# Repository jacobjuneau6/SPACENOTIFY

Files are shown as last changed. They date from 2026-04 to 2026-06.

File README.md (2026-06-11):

# SPACENOTIFY
SPACENOTIFY is a desktop dashboard that shows all space related activites including Launches, Landing and EVAs through the Launch Library 2 API.
# WHY
I designed SPACENOTIFY because I often can not look at my phone to check upcoming launches and I never want to miss one so this can sit on mydesk and as it has no controls can not be a distraction like a phone.
# Pictures
Final Front
Final Back
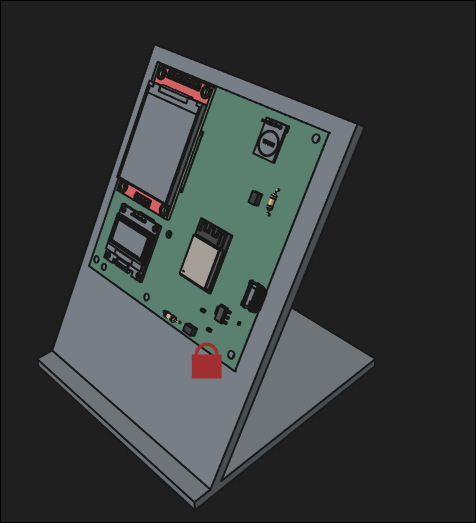
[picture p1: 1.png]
Assembly

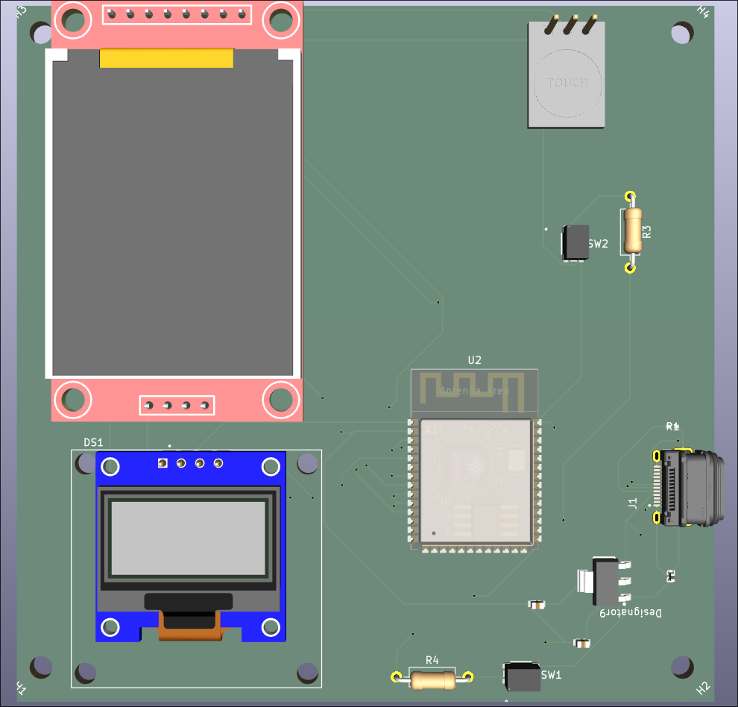
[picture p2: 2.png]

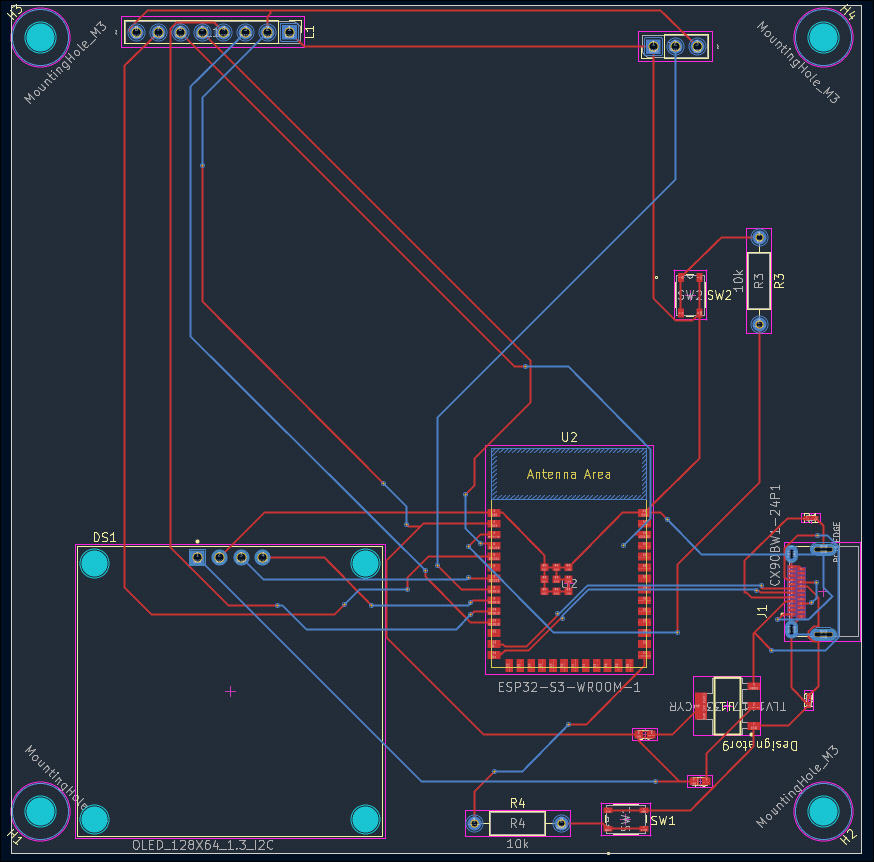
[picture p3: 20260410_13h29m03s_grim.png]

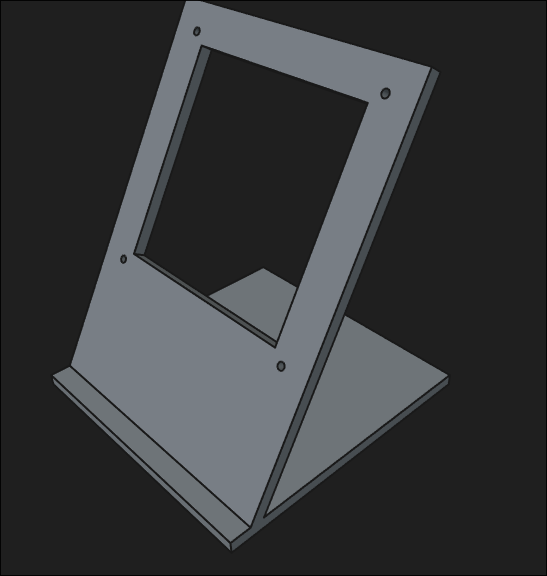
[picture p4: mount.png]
Mount

# BOM
| Name | Purpose | Quantity | Total Cost (USD) | Link | Distributor |
| --- | --- | --- | --- | --- | --- |
| GRM188R60J106KE47D 10uF capacitor | power filtering | 2 | 0.22 | https://www.digikey.com/en/products/detail/murata-electronics/GRM188R60J106KE47D/5797506 | Digikey |
| RC0402FR-075K1L 5.1k resistor | controll usb-c pd voltage | 2 | 0.20 | https://www.digikey.com/en/products/detail/yageo/RC0402FR-075K1L/726624 | Digikey |
| CX90BW1-24P1 USB c connector | power + data | 1 | 2.99 | https://www.digikey.com/en/products/detail/hirose-electric-co-ltd/CX90BW1-24P1/22566049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 | Digikey |
| SKRPABE010 button | to trigger boot and reset the esp32 | 2 | 0.42 | https://www.digikey.com/en/products/detail/alps-alpine/SKRPABE010/18768948 | Digikey |
| TLV1117-33IDCYR | LDO voltage regulator | 1 | 0.45 | https://www.digikey.com/en/products/detail/texas-instruments/TLV1117-33IDCYR/1216719 | Digikey |
| ESP32-S3-WROOM-1-N8R2 | Main MCU | 1 | 5.71 | https://www.digikey.com/en/products/detail/espressif-systems/ESP32-S3-WROOM-1-N8R2/15200058 | Digikey |
| Touch sensor | to allow UI interaction | 10 | 1.66 | https://www.aliexpress.us/item/3256806056841370.html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 | Aliexpress |
| 1.8in LCD | Displays main info | 1 | 2.88 | https://www.aliexpress.us/item/3256805953674718.html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 | Aliexpress |
| PCB | Holds the display and esp32 | 1 | 5.00 |  | PCBWAY |
| I2c display | shows the info | 1 | 1.99 | https://www.aliexpress.us/item/3256805899077405.html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 | Aliexpress |

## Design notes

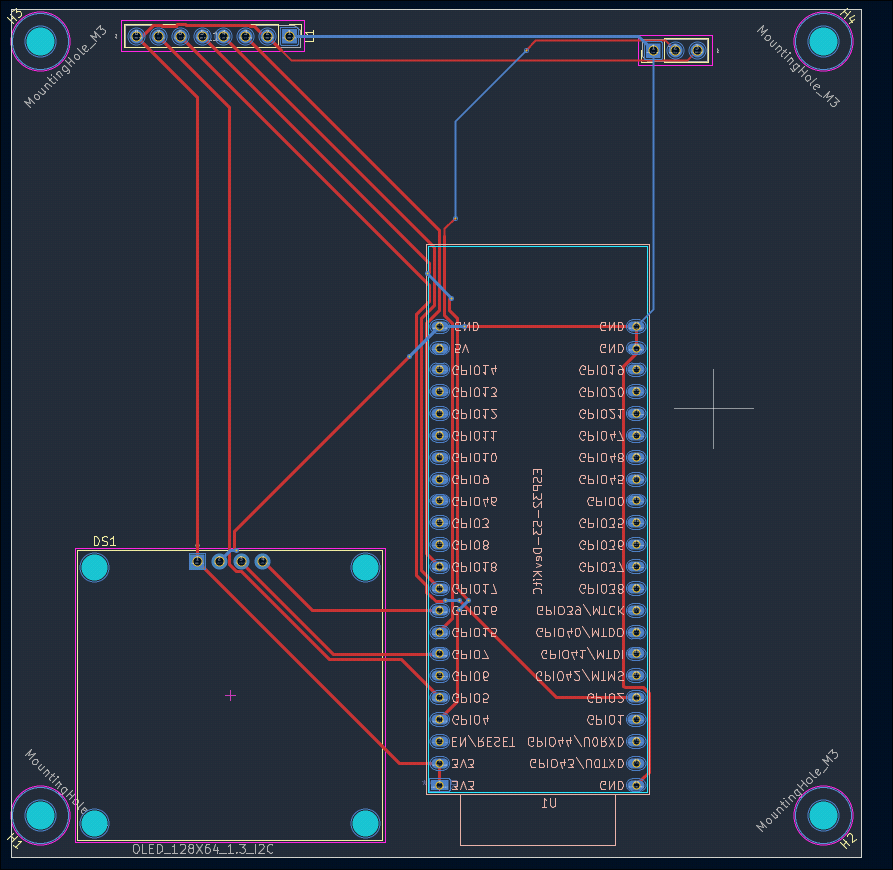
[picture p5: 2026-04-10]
20260410_11h46m12s_grim.png

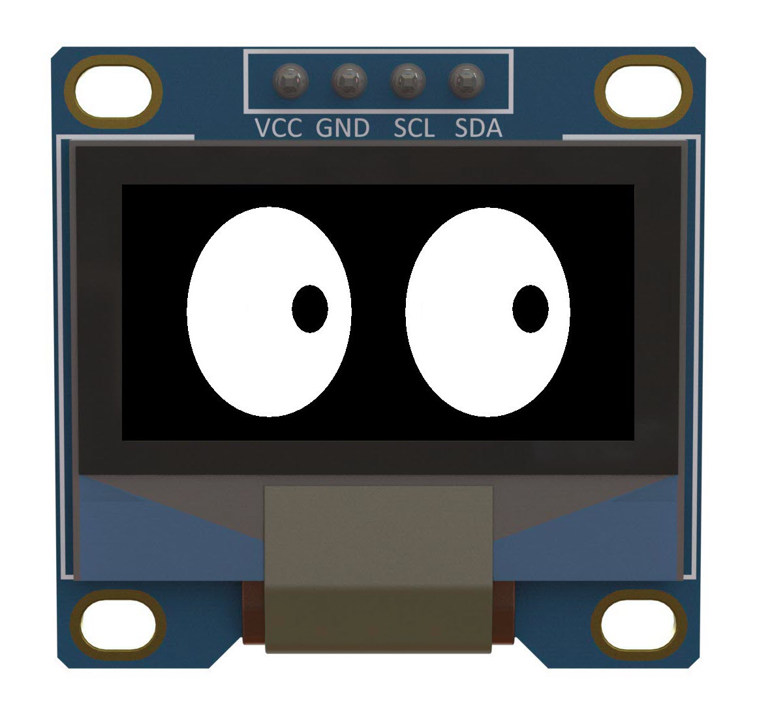
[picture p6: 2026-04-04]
v1/symbols/KiCad-SSD1306-128x64-0.1/oled-128-x-64-display-1.snapshot.15/OLED Eyes SLIDE.JPG

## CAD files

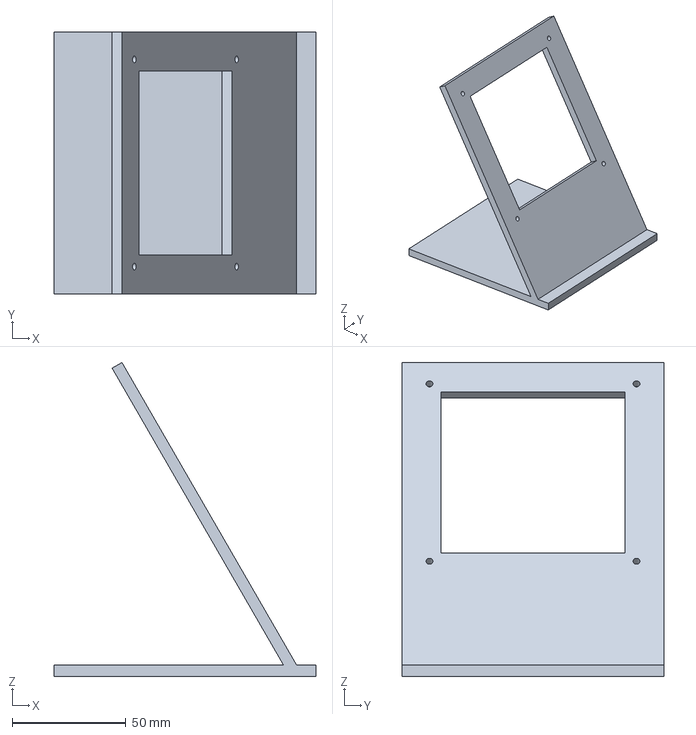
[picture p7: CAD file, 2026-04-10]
CAD/Base-v2.FCStd
115.0 x 115.0 x 138.0 mm

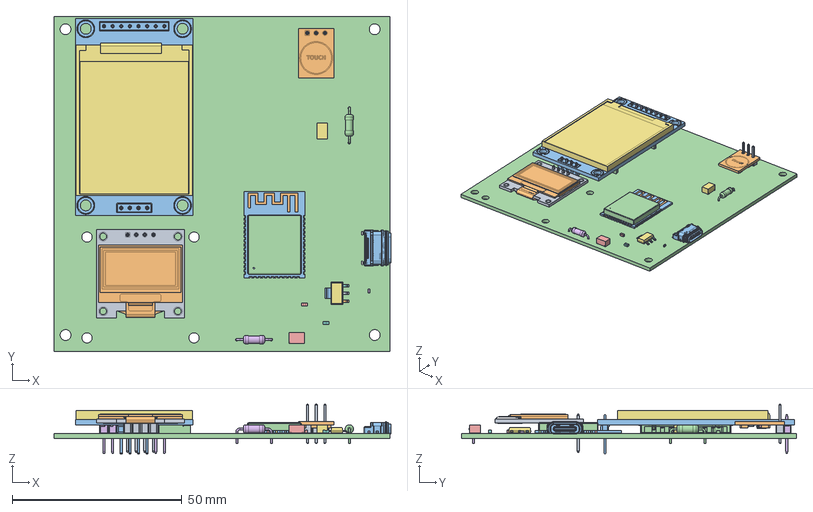
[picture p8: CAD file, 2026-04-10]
PCB.FCStd
99.2 x 98.6 x 14.6 mm
PinHeader_1x03_P2.54mm_Vertical
touch button TTP223
Board~fHK2
TopSilkscreen~fHK2
BottomSilkscreen~fHK2
R0603~R0603~fHK2
R0603~R0603~fHK001
R0603~R0603~fHK002
R0603~R0603~fHK003
SOT-23-3_L2.9-W1.3-P1.90-LS2.4-BR~SOT-23-3P_L2.9-W1.3-H1.0-LS2.4-P0.95~fHK2
HDR-TH_4P-P2.54-V-M~HDR-TH_4P-P2.54-M-LI-1X4P~fHK2
SD-CARD-SMD_SD-CARD-11P~SD-CARD-SMD_SD-CARD-11P~fHK2
C0603~C0603_L1.6-W0.8-H0.8~fHK2
HDR-TH_8P-P2.54-V-M~HDR-TH_8P-P2.54-V-M~fHK2
C0201_20210301.STEP^C0201_20210301.STEP_Submodel-C0201_part_DesignRootModel_PCB_ESP32-S3-WROOM-1_V1(2)_PCB_ESP32-S3-WROOM-1_V1
L0201_20210301.STEP^L0201_20210301.STEP_Submodel-L0201_part_DesignRootModel_PCB_ESP32-S3-WROOM-1_V1(2)_PCB_ESP32-S3-WROOM-1_V1
C0402_20210301.STEP^C0402_20210301.STEP_Submodel-C0402_part_DesignRootModel_PCB_ESP32-S3-WROOM-1_V1(2)_PCB_ESP32-S3-WROOM-1_V1
R0201_20210301.STEP^R0201_20210301.STEP_Submodel-R0201_part_DesignRootModel_PCB_ESP32-S3-WROOM-1_V1(2)_PCB_ESP32-S3-WROOM-1_V1
R0201_20210301.STEP^R0201_20210301.STEP_Submodel-R0201_part_DesignRootModel_PCB_ESP32-S3-WROOM-1_V1(2)_PCB_ESP32-S3-WROOM-1_V001
R0201_20210301.STEP^R0201_20210301.STEP_Submodel-R0201_part_DesignRootModel_PCB_ESP32-S3-WROOM-1_V1(2)_PCB_ESP32-S3-WROOM-1_V002
R0201_20210301.STEP^R0201_20210301.STEP_Submodel-R0201_part_DesignRootModel_PCB_ESP32-S3-WROOM-1_V1(2)_PCB_ESP32-S3-WROOM-1_V003
R0201_20210301.STEP^R0201_20210301.STEP_Submodel-R0201_part_DesignRootModel_PCB_ESP32-S3-WROOM-1_V1(2)_PCB_ESP32-S3-WROOM-1_V004
R0201_20210301.STEP^R0201_20210301.STEP_Submodel-R0201_part_DesignRootModel_PCB_ESP32-S3-WROOM-1_V1(2)_PCB_ESP32-S3-WROOM-1_V005
R0201_20210301.STEP^R0201_20210301.STEP_Submodel-R0201_part_DesignRootModel_PCB_ESP32-S3-WROOM-1_V1(2)_PCB_ESP32-S3-WROOM-1_V006
R0201_20210301.STEP^R0201_20210301.STEP_Submodel-R0201_part_DesignRootModel_PCB_ESP32-S3-WROOM-1_V1(2)_PCB_ESP32-S3-WROOM-1_V007
L0201_20210301.STEP^L0201_20210301.STEP_Submodel-L0201_part_DesignRootModel_PCB_ESP32-S3-WROOM-1_V1(2)_PCB_ESP32-S3-WROOM-1_V001
L0201_20210301.STEP^L0201_20210301.STEP_Submodel-L0201_part_DesignRootModel_PCB_ESP32-S3-WROOM-1_V1(2)_PCB_ESP32-S3-WROOM-1_V002
C0201_20210301.STEP^C0201_20210301.STEP_Submodel-C0201_part_DesignRootModel_PCB_ESP32-S3-WROOM-1_V1(2)_PCB_ESP32-S3-WROOM-1_V001
C0201_20210301.STEP^C0201_20210301.STEP_Submodel-C0201_part_DesignRootModel_PCB_ESP32-S3-WROOM-1_V1(2)_PCB_ESP32-S3-WROOM-1_V002
C0201_20210301.STEP^C0201_20210301.STEP_Submodel-C0201_part_DesignRootModel_PCB_ESP32-S3-WROOM-1_V1(2)_PCB_ESP32-S3-WROOM-1_V003
C0201_20210301.STEP^C0201_20210301.STEP_Submodel-C0201_part_DesignRootModel_PCB_ESP32-S3-WROOM-1_V1(2)_PCB_ESP32-S3-WROOM-1_V004
C0201_20210301.STEP^C0201_20210301.STEP_Submodel-C0201_part_DesignRootModel_PCB_ESP32-S3-WROOM-1_V1(2)_PCB_ESP32-S3-WROOM-1_V005
C0201_20210301.STEP^C0201_20210301.STEP_Submodel-C0201_part_DesignRootModel_PCB_ESP32-S3-WROOM-1_V1(2)_PCB_ESP32-S3-WROOM-1_V006
C0201_20210301.STEP^C0201_20210301.STEP_Submodel-C0201_part_DesignRootModel_PCB_ESP32-S3-WROOM-1_V1(2)_PCB_ESP32-S3-WROOM-1_V007
C0201_20210301.STEP^C0201_20210301.STEP_Submodel-C0201_part_DesignRootModel_PCB_ESP32-S3-WROOM-1_V1(2)_PCB_ESP32-S3-WROOM-1_V008
C0201_20210301.STEP^C0201_20210301.STEP_Submodel-C0201_part_DesignRootModel_PCB_ESP32-S3-WROOM-1_V1(2)_PCB_ESP32-S3-WROOM-1_V009
C0201_20210301.STEP^C0201_20210301.STEP_Submodel-C0201_part_DesignRootModel_PCB_ESP32-S3-WROOM-1_V1(2)_PCB_ESP32-S3-WROOM-1_V010
C0201_20210301.STEP^C0201_20210301.STEP_Submodel-C0201_part_DesignRootModel_PCB_ESP32-S3-WROOM-1_V1(2)_PCB_ESP32-S3-WROOM-1_V011
C0201_20210301.STEP^C0201_20210301.STEP_Submodel-C0201_part_DesignRootModel_PCB_ESP32-S3-WROOM-1_V1(2)_PCB_ESP32-S3-WROOM-1_V012
C0201_20210301.STEP^C0201_20210301.STEP_Submodel-C0201_part_DesignRootModel_PCB_ESP32-S3-WROOM-1_V1(2)_PCB_ESP32-S3-WROOM-1_V013
trace_1^Submodel-MINI-ANT-TYPEB_668419613_part_DesignRootModel_PCB_ESP32-S3-WROOM-1_V1(2)_PCB_ESP32-S3-WROOM-1_V1
DFN1006.STEP^DFN1006.STEP_Submodel-SOD882_part_DesignRootModel_PCB_ESP32-S3-WROOM-1_V1(2)_PCB_ESP32-S3-WROOM-1_V1
SOP8_rev1_20210308.STEP^SOP8_rev1_20210308.STEP_Submodel-SOP8_1P27_6P6_part_DesignRootModel_PCB_ESP32-S3-WROOM-1_V1(2)_PCB_ESP32-S3-WROOM-1_V1
XTAL3225_20210301.STEP^XTAL3225_20210301.STEP_Submodel-XTAL3225_part_DesignRootModel_PCB_ESP32-S3-WROOM-1_V1(2)_PCB_ESP32-S3-WROOM-1_V1
ESP32-S3_20210301.STEP^ESP32-S3_20210301.STEP_Submodel-QFN56_0P4_7_part_DesignRootModel_PCB_ESP32-S3-WROOM-1_V1(2)_PCB_ESP32-S3-WROOM-1_V1
uid__4-128^DesignRootModel_PCB_ESP32-S3-WROOM-1_V1(2)_PCB_ESP32-S3-WROOM-1_V1
uid__4-129^DesignRootModel_PCB_ESP32-S3-WROOM-1_V1(2)_PCB_ESP32-S3-WROOM-1_V1
uid__4-130^DesignRootModel_PCB_ESP32-S3-WROOM-1_V1(2)_PCB_ESP32-S3-WROOM-1_V1
uid__4-149^DesignRootModel_PCB_ESP32-S3-WROOM-1_V1(2)_PCB_ESP32-S3-WROOM-1_V1
uid__4-150^DesignRootModel_PCB_ESP32-S3-WROOM-1_V1(2)_PCB_ESP32-S3-WROOM-1_V1
uid__4-151^DesignRootModel_PCB_ESP32-S3-WROOM-1_V1(2)_PCB_ESP32-S3-WROOM-1_V1
uid__4-167^DesignRootModel_PCB_ESP32-S3-WROOM-1_V1(2)_PCB_ESP32-S3-WROOM-1_V1
uid__4-168^DesignRootModel_PCB_ESP32-S3-WROOM-1_V1(2)_PCB_ESP32-S3-WROOM-1_V1
uid__4-169^DesignRootModel_PCB_ESP32-S3-WROOM-1_V1(2)_PCB_ESP32-S3-WROOM-1_V1
uid__1-279^DesignRootModel_PCB_ESP32-S3-WROOM-1_V1(2)_PCB_ESP32-S3-WROOM-1_V1
uid__1-280^DesignRootModel_PCB_ESP32-S3-WROOM-1_V1(2)_PCB_ESP32-S3-WROOM-1_V1
uid__1-292^DesignRootModel_PCB_ESP32-S3-WROOM-1_V1(2)_PCB_ESP32-S3-WROOM-1_V1
uid__1-298^DesignRootModel_PCB_ESP32-S3-WROOM-1_V1(2)_PCB_ESP32-S3-WROOM-1_V1
uid__1-299^DesignRootModel_PCB_ESP32-S3-WROOM-1_V1(2)_PCB_ESP32-S3-WROOM-1_V1
uid__1-300^DesignRootModel_PCB_ESP32-S3-WROOM-1_V1(2)_PCB_ESP32-S3-WROOM-1_V1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

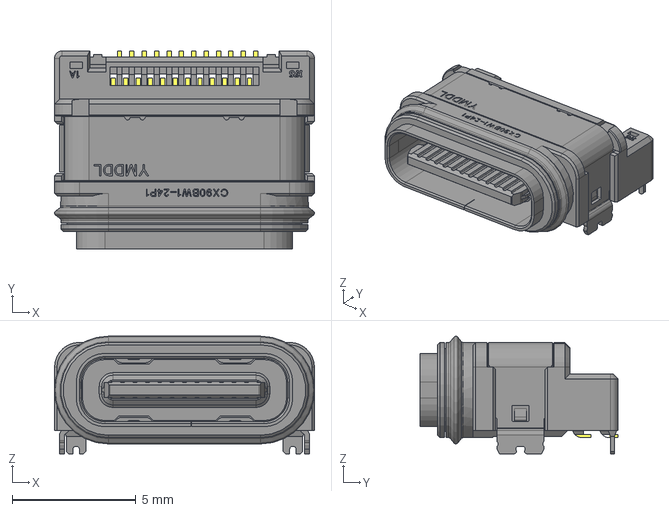
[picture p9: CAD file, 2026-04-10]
v1/symbols/CX90BW1-24P1/CX90BW1-24P1.step
10.5 x 8.00 x 4.75 mm

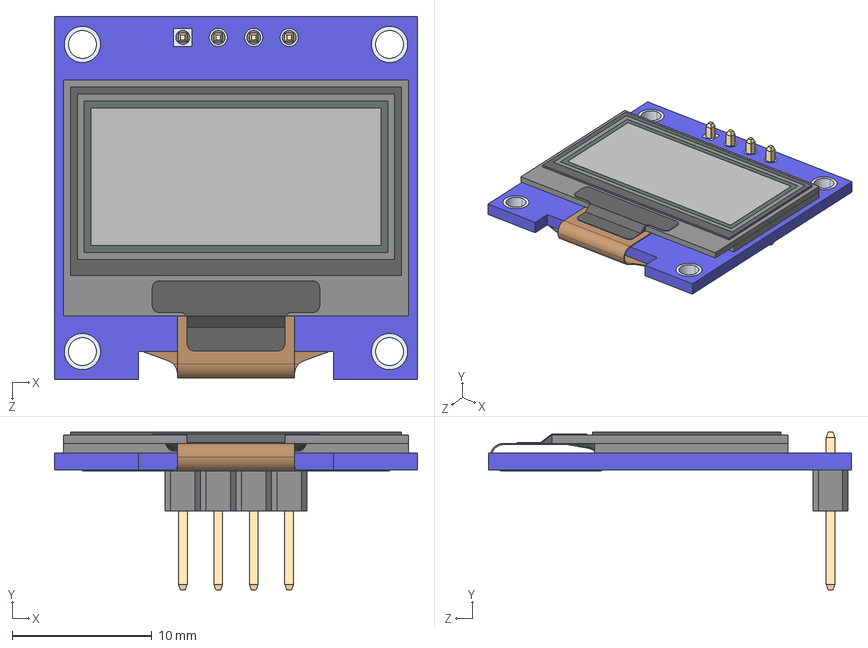
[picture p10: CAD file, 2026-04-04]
v1/symbols/DM-OLED096-636/DM-OLED096-636.step
26.0 x 11.3 x 26.0 mm
DM-OLED096-636_Module
DM-OLED096-636_Panel

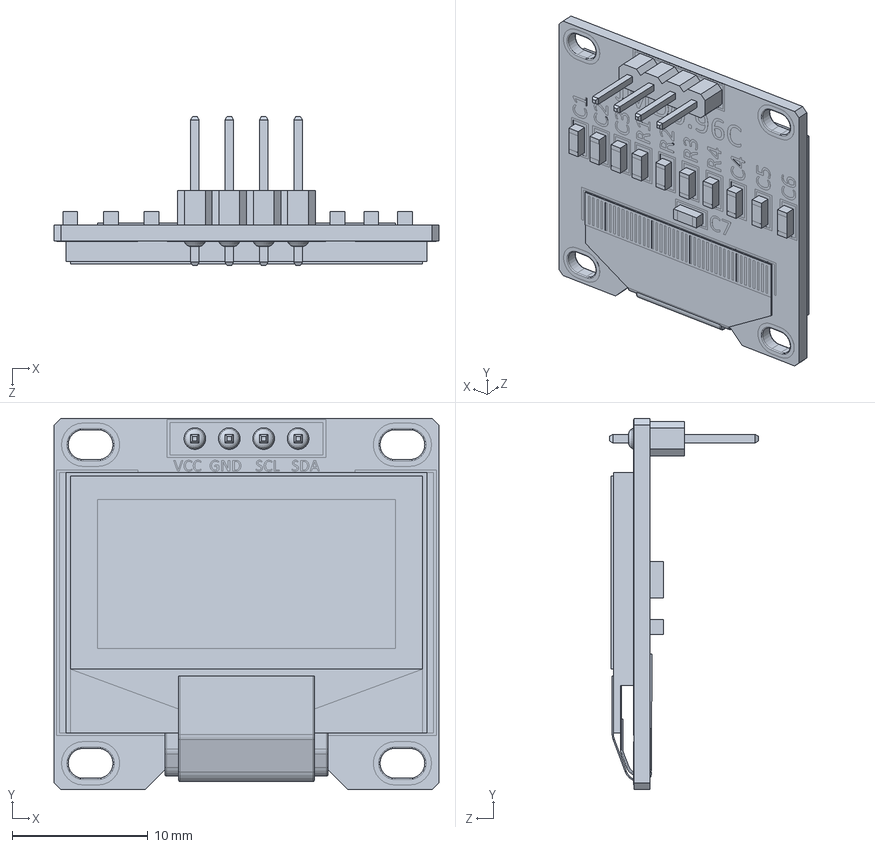
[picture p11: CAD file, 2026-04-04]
v1/symbols/KiCad-SSD1306-128x64-0.1/oled-128-x-64-display-1.snapshot.15/OLED Display 128x64.SLDPRT
28.4 x 27.4 x 11.0 mm

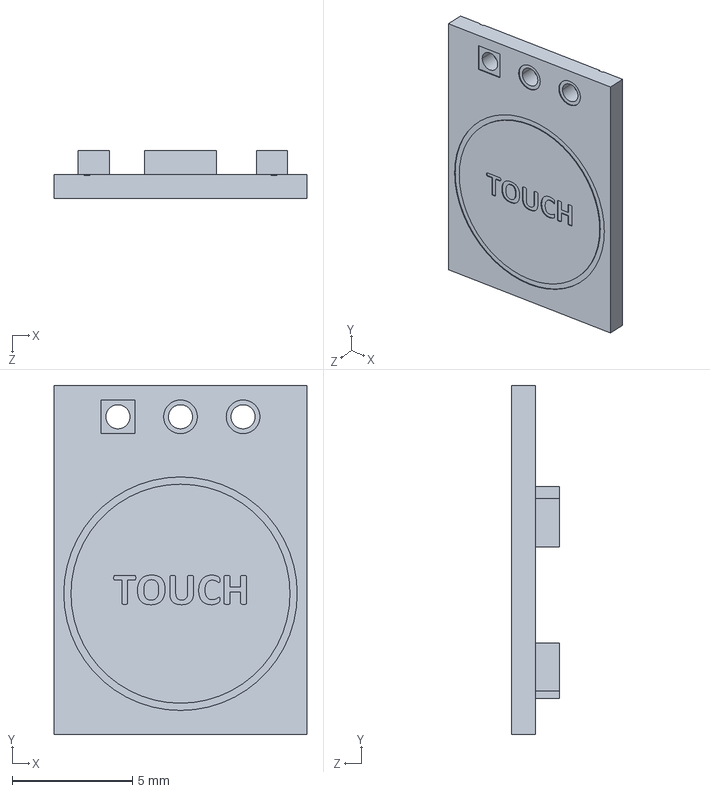
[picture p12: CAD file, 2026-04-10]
v1/symbols/touch button TTP223.STEP
10.5 x 14.5 x 2.00 mm

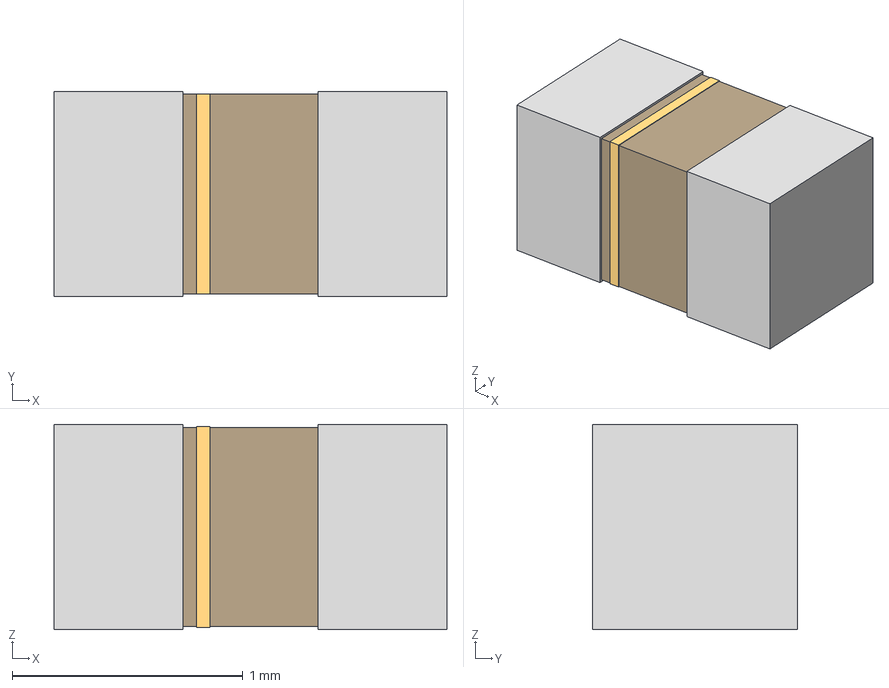
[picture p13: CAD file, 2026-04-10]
v1/symbols/ul_GRM188R60J106KE47D/CAP_GRM188_1608_MUR.step
1.70 x 0.888 x 0.889 mm

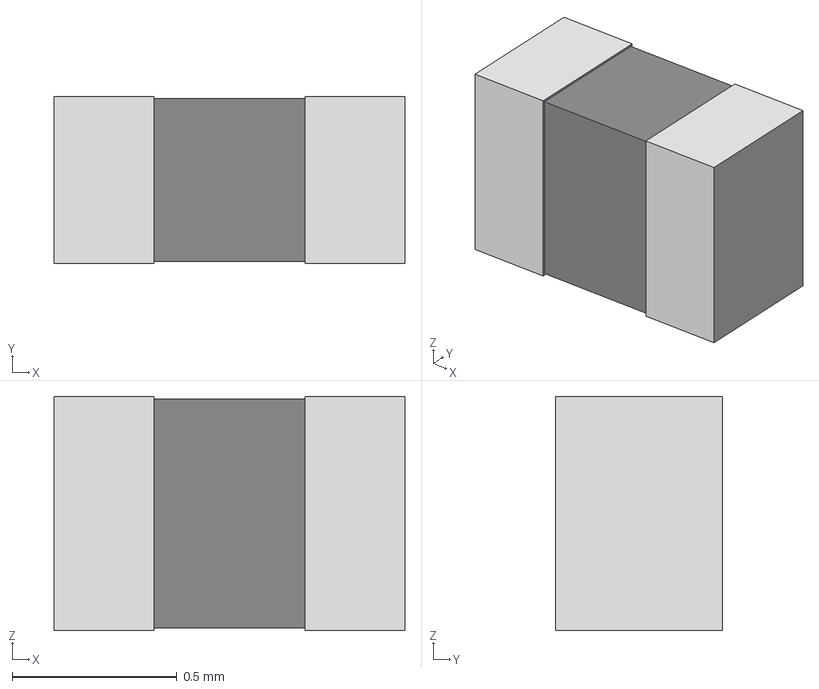
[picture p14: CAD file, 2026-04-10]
v1/symbols/ul_RC0402FR-075K1L/RC0402N_YAG.step
1.07 x 0.508 x 0.711 mm

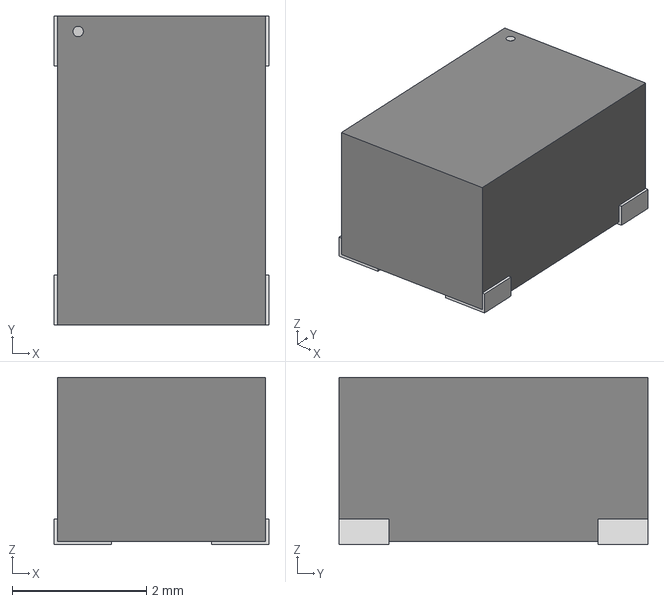
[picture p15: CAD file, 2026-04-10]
v1/symbols/ul_SKRPABE010/SW4_SKRPABE010_ALPS.step
3.20 x 4.60 x 2.49 mm

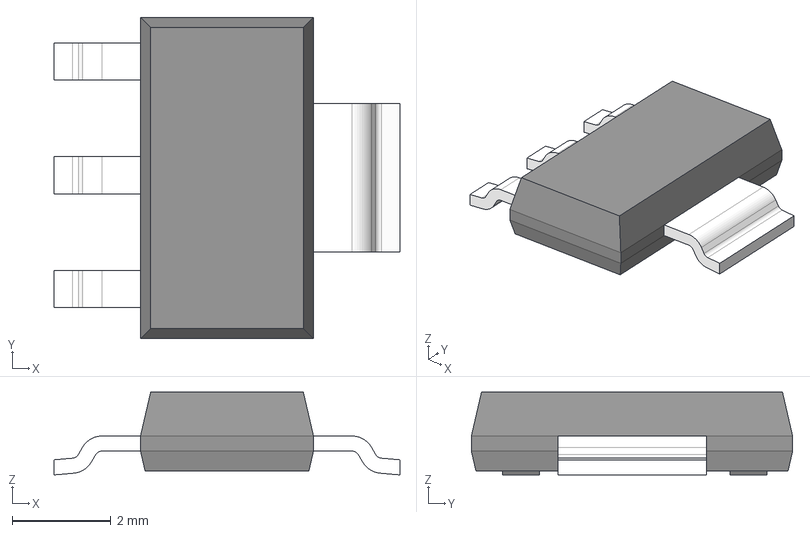
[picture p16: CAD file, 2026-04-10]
v1/symbols/ul_TLV1117-33IDCYR/DCY0004A.stp
7.00 x 6.50 x 1.68 mm
BODY-SOT
LEAD-SOT x 3
LEAD-SOT-WIDE
PIN1-ID

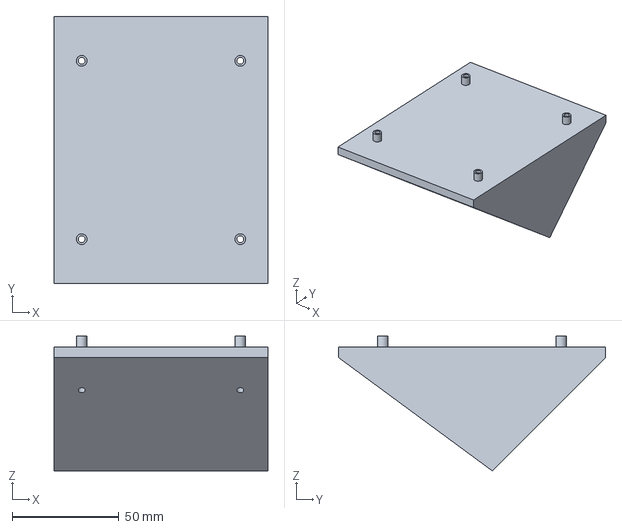
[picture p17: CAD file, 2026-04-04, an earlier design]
CAD/Base.FCStd
100.0 x 125.0 x 63.0 mm

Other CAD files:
CAD/Assembly.FCStd
CAD/Base-v2-Body.step
CAD/PCB.FCStd
v1/symbols/KiCad-SSD1306-128x64-0.1/oled-128-x-64-display-1.snapshot.15/OLED Display 128x64.STL

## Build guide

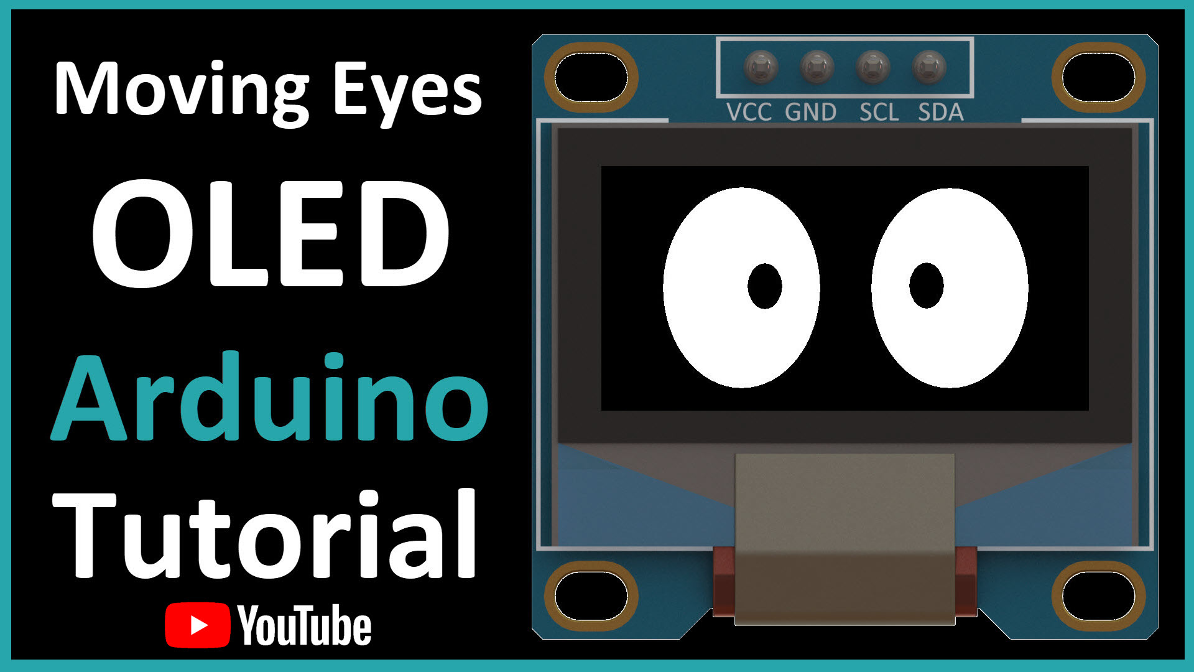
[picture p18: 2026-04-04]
v1/symbols/KiCad-SSD1306-128x64-0.1/oled-128-x-64-display-1.snapshot.15/YouTube OLED Moving Eyes Arduino Tutorial.JPG

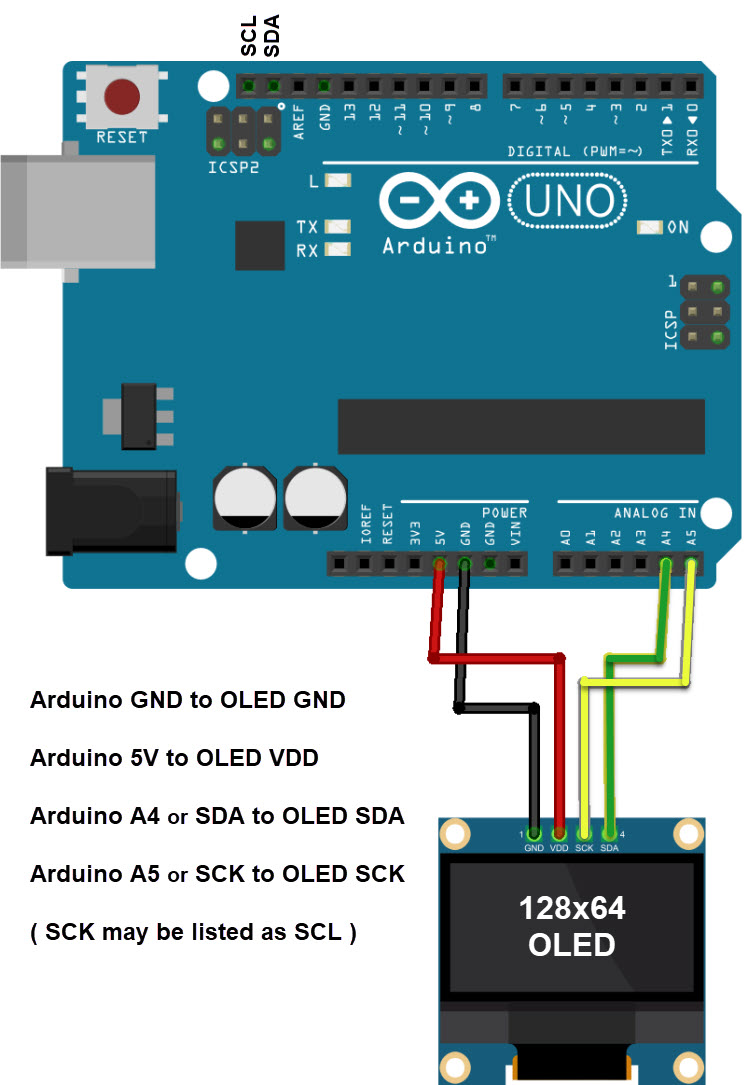
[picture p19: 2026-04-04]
v1/symbols/KiCad-SSD1306-128x64-0.1/oled-128-x-64-display-1.snapshot.15/Arduino Wiring to OLED I2C.jpg

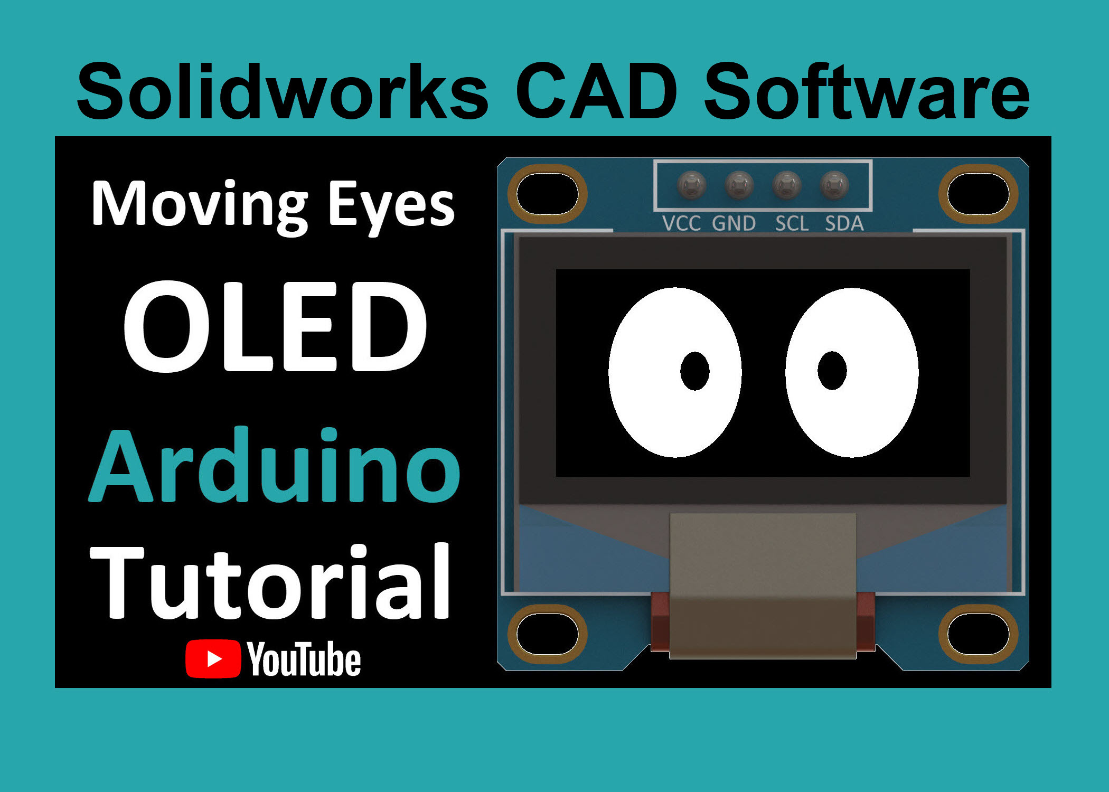
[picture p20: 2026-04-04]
v1/symbols/KiCad-SSD1306-128x64-0.1/oled-128-x-64-display-1.snapshot.15/YouTube OLED Eyes Arduino Tutorial.JPG

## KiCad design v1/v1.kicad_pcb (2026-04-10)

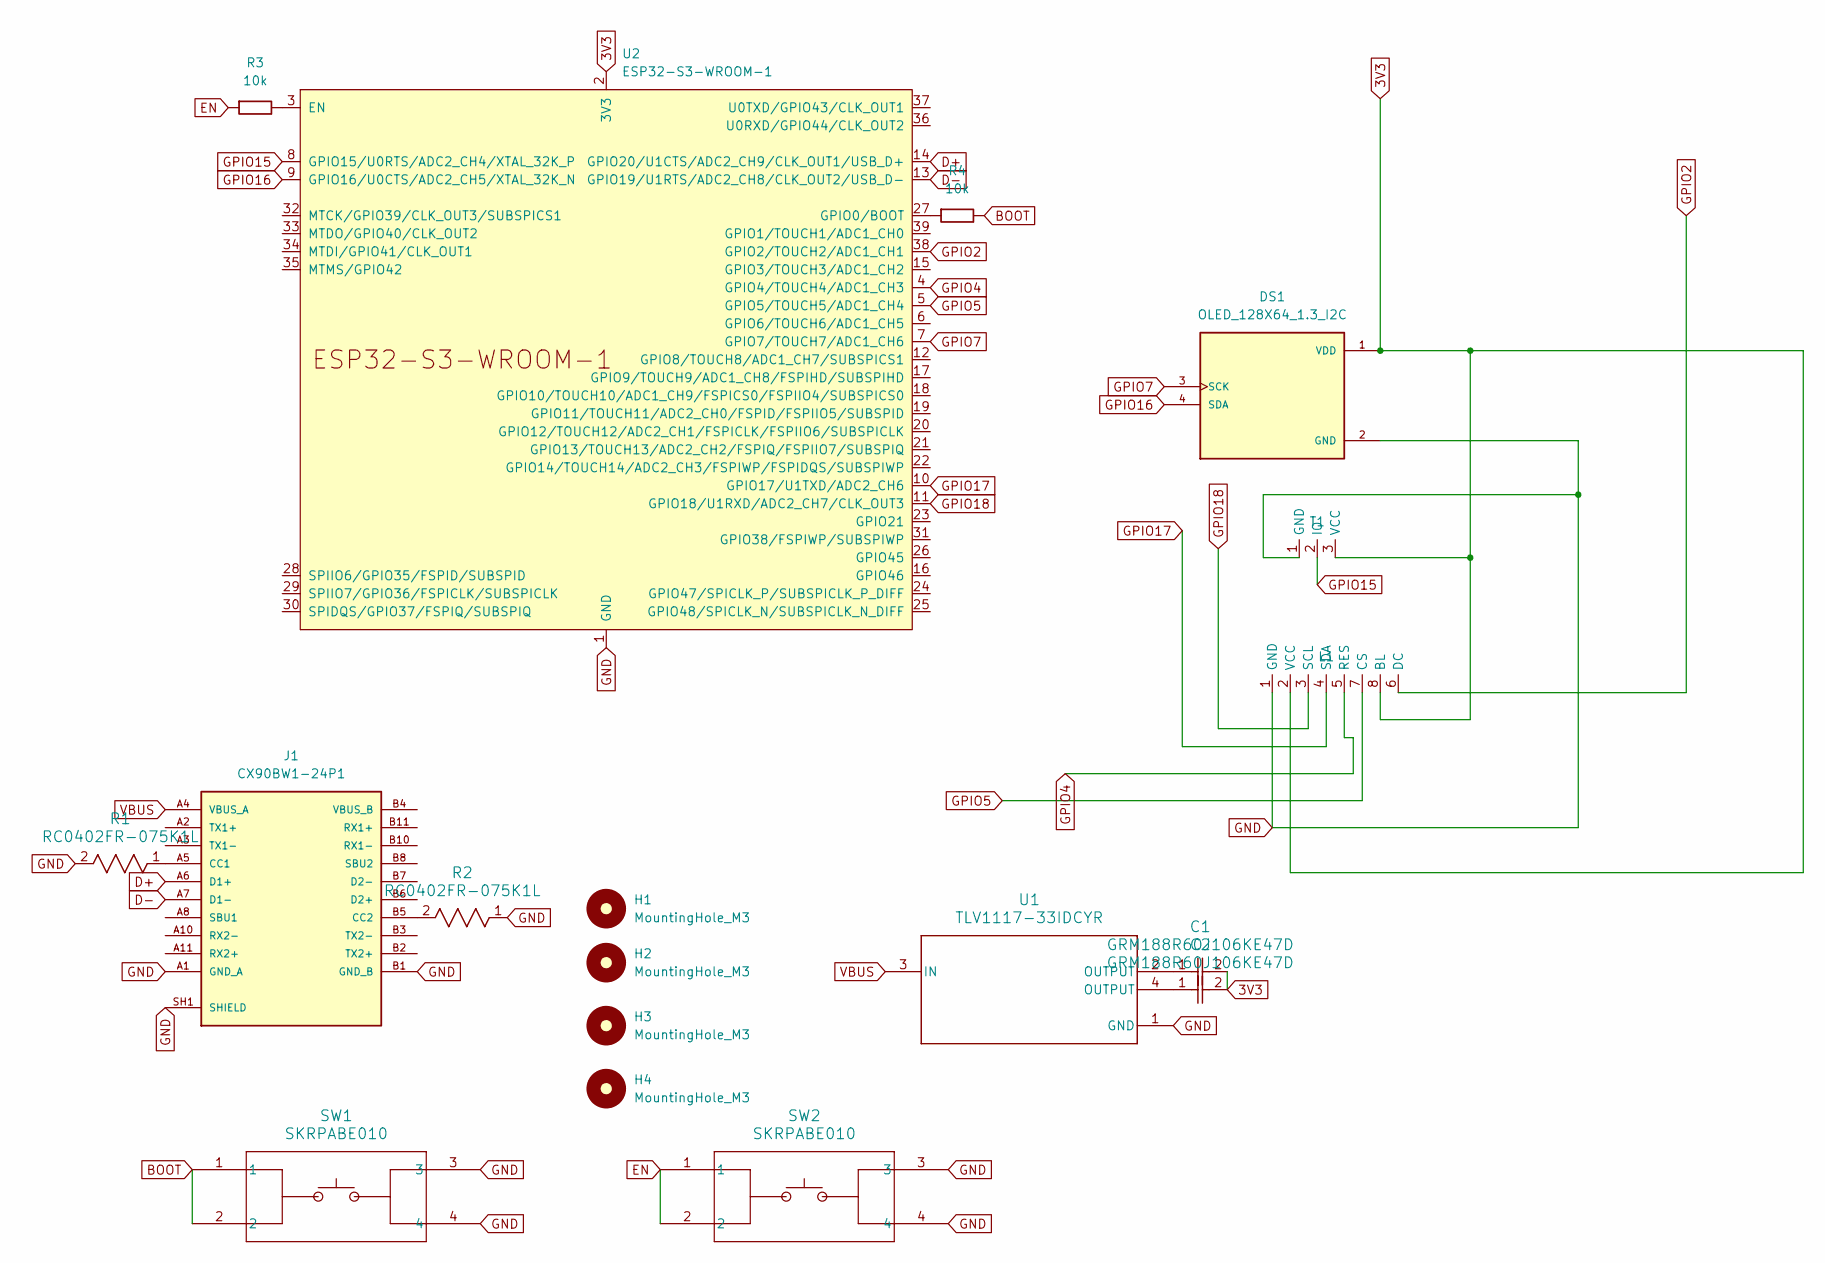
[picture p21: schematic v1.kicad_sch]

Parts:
C1, C2: GRM188R60J106KE47D; CAP_GRM188_1608_MUR
DS1: OLED_128X64_1.3_I2C; LCD_OLED_128X64_1.3_I2C; PARTREV NA
H1, H2, H3, H4: MountingHole_M3; MountingHole_3.2mm_M3
J1: CX90BW1-24P1; HIROSE_CX90BW1-24P1; PARTREV 24.05.01; DigiKey_Part_Number 26-CX90BW1-24P1CT-ND
L1: PinHeader_1x08_P2.54mm_Vertical
R1, R2: RC0402FR-075K1L; RC0402N_YAG
R3, R4: 10k; R_Axial_DIN0207_L6.3mm_D2.5mm_P10.16mm_Horizontal
SW1, SW2: SKRPABE010; SW4_SKRPABE010_ALPS
T1: PinHeader_1x03_P2.54mm_Vertical
U1: TLV1117-33IDCYR; DCY0004A_L
U2: ESP32-S3-WROOM-1

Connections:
3V3: C1.2, C2.2, DS1.1 (VDD), L1.2 (VCC), L1.8 (BL), T1.3 (VCC), U2.2 (3V3)
BOOT: R4.2, SW1.1, SW1.2
D+: J1.A6 (D1+), U2.14 (GPIO20/U1CTS/ADC2_CH9/CLK_OUT1/USB_D+)
D-: J1.A7 (D1-), U2.13 (GPIO19/U1RTS/ADC2_CH8/CLK_OUT2/USB_D-)
EN: R3.1, SW2.1, SW2.2
GND: DS1.2 (GND), J1.A1 (GND_A), J1.A12 (GND_A), J1.B1 (GND_B), J1.B12 (GND_B), J1.SH1 (SHIELD), J1.SH2 (SHIELD), J1.SH3 (SHIELD), J1.SH4 (SHIELD), L1.1 (GND), R1.2, R2.1, SW1.3, SW1.4, SW2.3, SW2.4, T1.1 (GND), U1.1 (GND), U2.1 (GND), U2.40 (GND), U2.41 (GND)
GPIO2: L1.6 (DC), U2.38 (GPIO2/TOUCH2/ADC1_CH1)
GPIO4: L1.5 (RES), U2.4 (GPIO4/TOUCH4/ADC1_CH3)
GPIO5: L1.7 (CS), U2.5 (GPIO5/TOUCH5/ADC1_CH4)
GPIO7: DS1.3 (SCK), U2.7 (GPIO7/TOUCH7/ADC1_CH6)
GPIO15: T1.2 (IO), U2.8 (GPIO15/U0RTS/ADC2_CH4/XTAL_32K_P)
GPIO16: DS1.4 (SDA), U2.9 (GPIO16/U0CTS/ADC2_CH5/XTAL_32K_N)
GPIO17: L1.4 (SDA), U2.10 (GPIO17/U1TXD/ADC2_CH6)
GPIO18: L1.3 (SCL), U2.11 (GPIO18/U1RXD/ADC2_CH7/CLK_OUT3)
unnamed: C1.1, U1.2 (OUTPUT)
unnamed: C2.1, U1.4 (OUTPUT)
unnamed: J1.A5 (CC1), R1.1
unnamed: J1.B5 (CC2), R2.2
unnamed: R3.2, U2.3 (EN)
unnamed: R4.1, U2.27 (GPIO0/BOOT)
VBUS: J1.A4 (VBUS_A), J1.A9 (VBUS_A), U1.3 (IN)
VBUS_B: J1.B4 (VBUS_B), J1.B9 (VBUS_B)

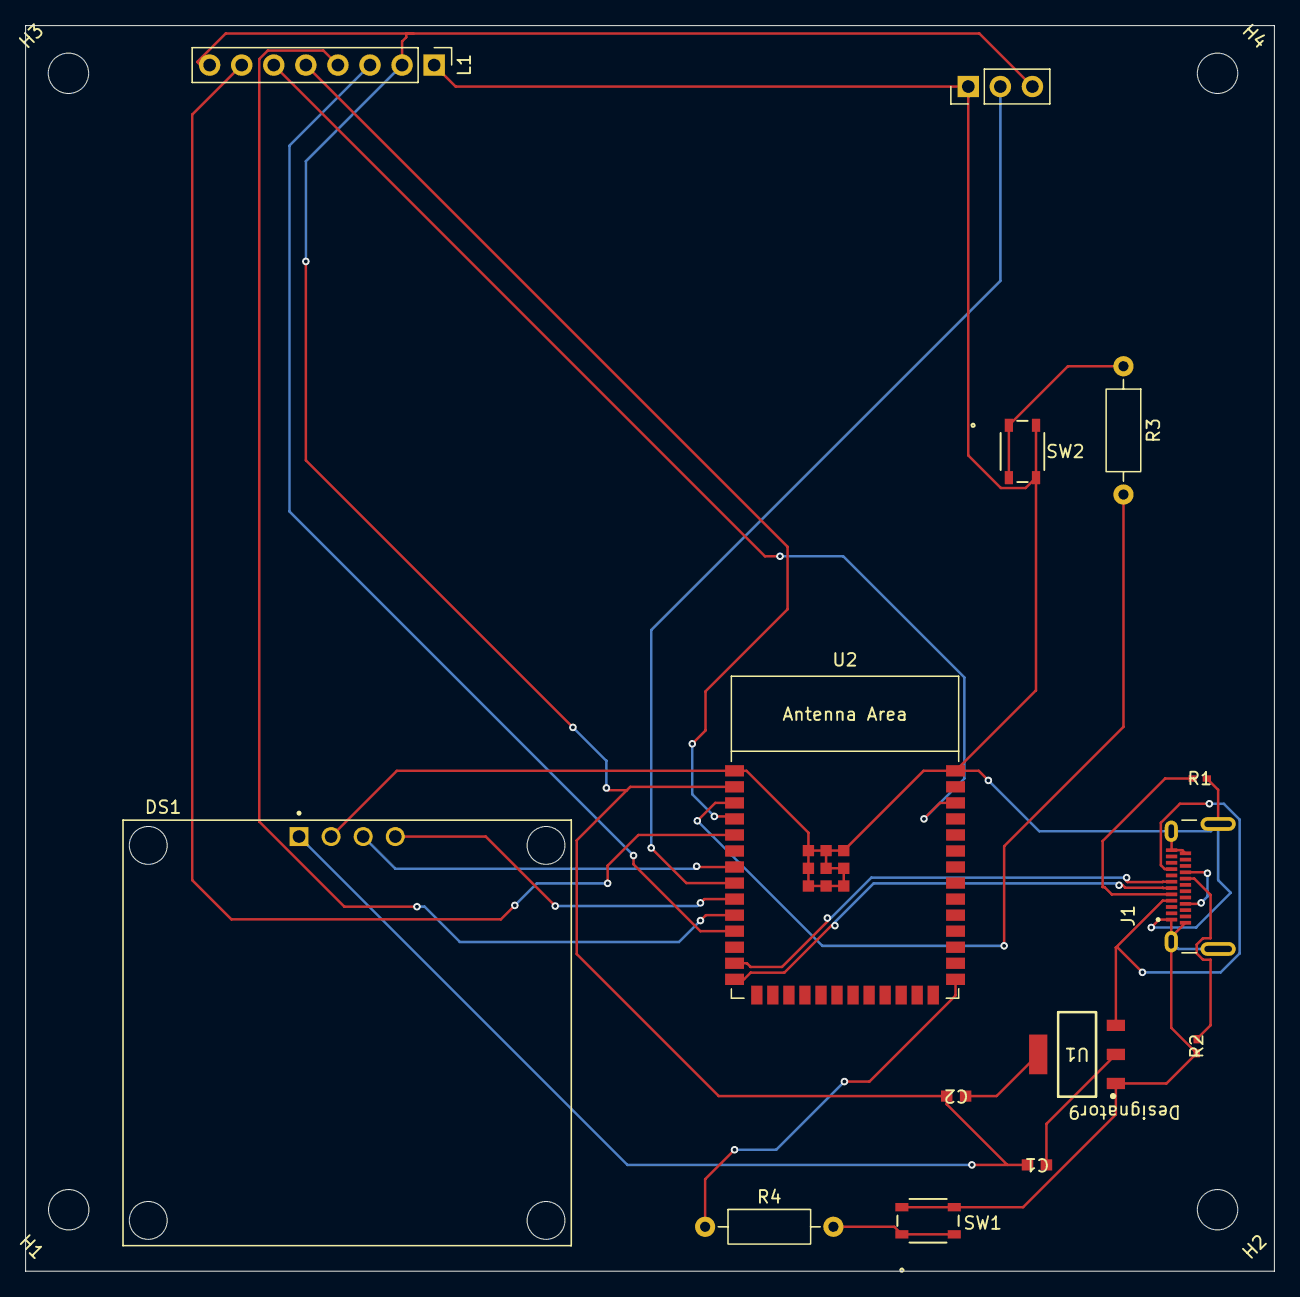
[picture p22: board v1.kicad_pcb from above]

Board: 2 copper layers, 98.9 x 98.6 mm, 18 parts (0 on the bottom side), 22 nets.

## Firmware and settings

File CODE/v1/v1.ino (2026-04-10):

#include <WiFi.h>
#include <HTTPClient.h>
#include <ArduinoJson.h>
#include <Adafruit_GFX.h>
#include <Adafruit_ST7735.h>
#include <Adafruit_SSD1306.h>
#include <SPI.h>
#include <Wire.h>
#include <WiFiUdp.h>
#include <NTPClient.h>

// -------- WIFI --------
const char* ssid = "YOUR_SSID";
const char* password = "YOUR_PASSWORD";

// -------- ST7735 --------
#define TFT_CS   5
#define TFT_DC   2
#define TFT_RST  4
Adafruit_ST7735 tft = Adafruit_ST7735(TFT_CS, TFT_DC, TFT_RST);

// -------- OLED --------
#define SCREEN_WIDTH 128
#define SCREEN_HEIGHT 64
Adafruit_SSD1306 oled(SCREEN_WIDTH, SCREEN_HEIGHT, &Wire, -1);

// -------- TOUCH --------
#define TOUCH_PIN 15

// -------- NTP --------
WiFiUDP ntpUDP;
NTPClient timeClient(ntpUDP, "pool.ntp.org", 0, 1000);

// -------- API --------
const char* apiUrl = "https://fdo.rocketlaunch.live/json/launches/next/5";

// -------- DATA --------
struct Launch {
  String name;
  String provider;
  String vehicle;
  String location;
  time_t epoch;
};

Launch launches[5];
int currentIndex = 0;
bool detailView = false;

// -------- TOUCH STATE --------
bool lastTouch = LOW;
unsigned long touchStart = 0;

// -------- AUTO SWITCH --------
bool liftoffHandled = false;
unsigned long liftoffTime = 0;

// -------- REFRESH CONTROL --------
unsigned long lastRefresh = 0;
const unsigned long NORMAL_REFRESH = 600000; // 10 min

// -------- TIME PARSE --------
time_t parseISOTime(String iso) {
  struct tm t;
  sscanf(iso.c_str(), "%d-%d-%dT%d:%d:%d",
         &t.tm_year, &t.tm_mon, &t.tm_mday,
         &t.tm_hour, &t.tm_min, &t.tm_sec);

  t.tm_year -= 1900;
  t.tm_mon -= 1;
  return mktime(&t);
}

// -------- FETCH --------
void fetchLaunches() {
  HTTPClient http;
  http.begin(apiUrl);

  if (http.GET() == 200) {
    DynamicJsonDocument doc(16384);
    deserializeJson(doc, http.getString());

    JsonArray result = doc["result"];

    for (int i = 0; i < 5; i++) {
      launches[i].name = result[i]["name"].as<String>();
      launches[i].provider = result[i]["provider"]["name"].as<String>();
      launches[i].vehicle = result[i]["vehicle"]["name"].as<String>();
      launches[i].location = result[i]["pad"]["location"]["name"].as<String>();

      String iso = result[i]["date_utc"].as<String>();
      launches[i].epoch = parseISOTime(iso);
    }
  }

  http.end();
  lastRefresh = millis();
}

// -------- COUNTDOWN --------
String getCountdown(time_t target) {
  long diff = target - timeClient.getEpochTime();

  if (diff <= 0) return "LIFTOFF";

  int h = diff / 3600;
  int m = (diff % 3600) / 60;
  int s = diff % 60;

  char buf[20];
  sprintf(buf, "T-%02d:%02d:%02d", h, m, s);
  return String(buf);
}

// -------- DRAW LIST --------
void drawList() {
  tft.fillScreen(ST77XX_BLACK);
  tft.setTextSize(1);

  for (int i = 0; i < 5; i++) {
    int y = i * 25;

    if (i == currentIndex) {
      tft.fillRect(0, y, 160, 25, ST77XX_BLUE);
      tft.setTextColor(ST77XX_BLACK);
    } else {
      tft.setTextColor(ST77XX_WHITE);
    }

    tft.setCursor(2, y + 2);
    tft.print(launches[i].name.substring(0, 18));

    tft.setCursor(2, y + 14);
    tft.print(getCountdown(launches[i].epoch));
  }
}

// -------- DETAIL --------
void drawDetail() {
  tft.fillScreen(ST77XX_BLACK);
  tft.setTextColor(ST77XX_WHITE);

  Launch l = launches[currentIndex];

  tft.setCursor(0, 0);
  tft.println(l.name);
  tft.println(l.vehicle);
  tft.println(l.provider);
  tft.println(l.location);

  tft.println();
  tft.setTextSize(2);
  tft.println(getCountdown(l.epoch));
  tft.setTextSize(1);
}

// -------- OLED --------
void drawOLED() {
  oled.clearDisplay();

  Launch l = launches[0];

  oled.setTextSize(1);
  oled.setCursor(0, 0);
  oled.println("NEXT:");

  oled.println(l.name.substring(0, 16));

  oled.setTextSize(2);
  oled.setCursor(0, 30);
  oled.println(getCountdown(l.epoch));

  oled.display();
}

// -------- TOUCH --------
void handleTouch() {
  bool state = digitalRead(TOUCH_PIN);

  if (state == HIGH && lastTouch == LOW)
    touchStart = millis();

  if (state == LOW && lastTouch == HIGH) {
    unsigned long d = millis() - touchStart;

    if (d > 800) {
      detailView = !detailView;
    } else {
      if (!detailView)
        currentIndex = (currentIndex + 1) % 5;
    }
  }

  lastTouch = state;
}

// -------- AUTO SWITCH --------
void handleAutoSwitch() {
  long diff = launches[0].epoch - timeClient.getEpochTime();

  if (diff <= 0 && !liftoffHandled) {
    liftoffHandled = true;
    liftoffTime = millis();
  }

  if (liftoffHandled && millis() - liftoffTime > 5000) {
    fetchLaunches(); // refresh instead of shifting

    currentIndex = 0;
    detailView = false;

    liftoffHandled = false;
  }
}

// -------- SMART REFRESH --------
void handleSmartRefresh() {
  long diff = launches[0].epoch - timeClient.getEpochTime();

  // Normal refresh every 10 min
  if (millis() - lastRefresh > NORMAL_REFRESH) {
    fetchLaunches();
  }

  // If launch is soon (<15 min), refresh more often
  if (diff > 0 && diff < 900) {
    if (millis() - lastRefresh > 60000) { // every 1 min
      fetchLaunches();
    }
  }
}

// -------- SETUP --------
void setup() {
  Serial.begin(115200);

  pinMode(TOUCH_PIN, INPUT);

  tft.initR(INITR_BLACKTAB);
  tft.setRotation(1);

  Wire.begin(21, 22);
  oled.begin(SSD1306_SWITCHCAPVCC, 0x3C);

  WiFi.begin(ssid, password);
  while (WiFi.status() != WL_CONNECTED) delay(500);

  timeClient.begin();
  timeClient.update();

  fetchLaunches();
}

// -------- LOOP --------
void loop() {
  handleTouch();
  timeClient.update();

  handleAutoSwitch();
  handleSmartRefresh();

  static unsigned long lastDraw = 0;

  if (millis() - lastDraw > 1000) {
    if (detailView) drawDetail();
    else drawList();

    drawOLED();

    lastDraw = millis();
  }
}

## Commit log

2026-04-10 code, new pcb and bom
    [Assembly.FCStd, Base-v2.FCStd, PCB.FCStd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]
2026-04-10 new PCB schematic, readme, BOM
    [Assembly.FCStd, Base-v2-Body.step, Base-v2.FCStd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]
